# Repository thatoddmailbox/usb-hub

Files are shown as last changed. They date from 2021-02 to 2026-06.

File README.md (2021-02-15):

# usb-hub
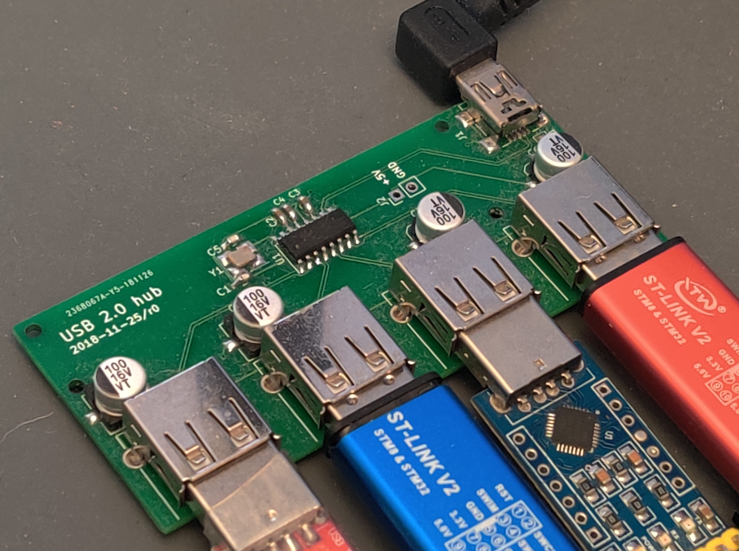
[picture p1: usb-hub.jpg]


A four-port USB 2.0 hub based around the [CoreChips SL2.1A](https://datasheet.lcsc.com/szlcsc/1811151645_CoreChips-SL2-1A_C192893.pdf) IC.

You can choose whether it's bus powered or externally powered with JP1. Soldering JP1 closed selects bus power, while leaving JP1 open means devices are powered with external power, which can be provided through J2.

Note that an external 12 MHz crystal is provided for the SL2.1A. The datasheet claims that the chip also has an internal 12 MHz oscillator that you can use by connecting XIN (pin 16 of the SL2.1) to ground. It's recommended to use the external one, though, as it's more stable. (see the red Chinese text on page 5 of the datasheet)

The port closest to the upstream mini-USB port is port number 1, and the remaining ports are numbered 2 through 4.

## Assembly
This board is fairly easy to assemble with a soldering iron, flux, and solder wick. The main thing to watch out for is that the two sets of electrolytic capacitors, near the output ports, have opposite polarities. The silkscreen has the positive side labeled, so you should make sure the negative side of the capacitor (with the black stripe) is opposite of the positive side (as labeled by a plus on the board).

## Useful links
* [Rev 0 schematic](./mfg/rev0/usb-hub.pdf)
* [Rev 0 BOM](./mfg/rev0/usb-hub.csv)

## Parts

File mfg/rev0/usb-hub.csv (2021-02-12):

Reference | Value | Footprint | Datasheet
U1 | SL2.1A | Housings_SOIC:SOIC-16_3.9x9.9mm_Pitch1.27mm
J1 | USB_B_Mini | Connectors:USB_Mini-B | ~
JP1 | SolderJumper_2_Bridged | Jumper:SolderJumper-2_P1.3mm_Open_TrianglePad1.0x1.5mm | ~
J3 | USB_A | Connectors:USB_A | ~
J2 | Conn_01x02 | Pin_Headers:Pin_Header_Straight_1x02_Pitch2.54mm | ~
J4 | USB_A | Connectors:USB_A | ~
J5 | USB_A | Connectors:USB_A | ~
J6 | USB_A | Connectors:USB_A | ~
Y1 | 12MHz | Crystals:Crystal_SMD_3225-4pin_3.2x2.5mm_HandSoldering | ~
C1 | 12pF | Capacitors_SMD:C_0603_HandSoldering | ~
C5 | 12pF | Capacitors_SMD:C_0603_HandSoldering | ~
C2 | 10uF | Capacitors_SMD:C_0603_HandSoldering | ~
C4 | 10uF | Capacitors_SMD:C_0603_HandSoldering | ~
C3 | 10uF | Capacitors_SMD:C_0603_HandSoldering | ~
C6 | 100uF | Capacitors_SMD:CP_Elec_6.3x5.3 | ~
C7 | 100uF | Capacitors_SMD:CP_Elec_6.3x5.3 | ~
C8 | 100uF | Capacitors_SMD:CP_Elec_6.3x5.3 | ~
C9 | 100uF | Capacitors_SMD:CP_Elec_6.3x5.3 | ~

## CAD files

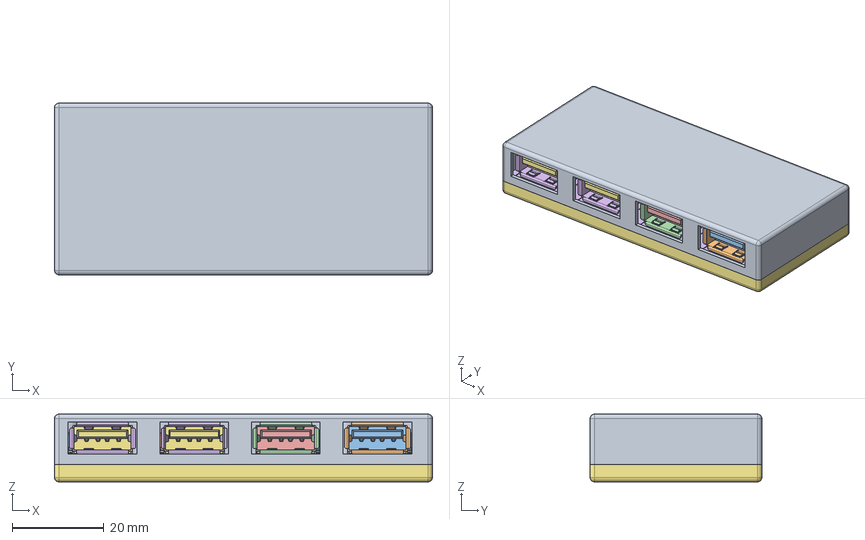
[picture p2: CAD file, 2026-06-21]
case/usb-hub-case.FCStd
82.5 x 37.5 x 14.8 mm
Top Case
USB_A_Molex_67643_Horizontal
USB_A_Molex_67643_Horizontal001
USB_A_Molex_67643_Horizontal002
USB_A_Molex_67643_Horizontal003
USB_A_Molex_67643_Horizontal004
USB_A_Molex_67643_Horizontal005
USB_A_Molex_67643_Horizontal006
USB_A_Molex_67643_Horizontal007
USB_A_Molex_67643_Horizontal008
USB_A_Molex_67643_Horizontal009
USB_A_Molex_67643_Horizontal012
USB_A_Molex_67643_Horizontal013
USB_A_Molex_67643_Horizontal014
USB_A_Molex_67643_Horizontal015
USB_A_Molex_67643_Horizontal016
USB_A_Molex_67643_Horizontal017
USB_A_Molex_67643_Horizontal018
USB_A_Molex_67643_Horizontal019
USB_A_Molex_67643_Horizontal020
USB_A_Molex_67643_Horizontal021
USB_A_Molex_67643_Horizontal024
USB_A_Molex_67643_Horizontal025
USB_A_Molex_67643_Horizontal026
USB_A_Molex_67643_Horizontal027
USB_A_Molex_67643_Horizontal028
USB_A_Molex_67643_Horizontal029
USB_A_Molex_67643_Horizontal030
USB_A_Molex_67643_Horizontal031
USB_A_Molex_67643_Horizontal032
USB_A_Molex_67643_Horizontal033
CP_Elec_63x53
CP_Elec_63x001
CP_Elec_63x002
CP_Elec_63x003
Crystal_SMD_3225-4Pin_3.2x2.5mm_HandSoldering
USB_Mini-B_Lumberg_2486_01_Horizontal
USB_A_Molex_67643_Horizontal036
USB_A_Molex_67643_Horizontal037
USB_A_Molex_67643_Horizontal038
USB_A_Molex_67643_Horizontal039
USB_A_Molex_67643_Horizontal040
USB_A_Molex_67643_Horizontal041
USB_A_Molex_67643_Horizontal042
USB_A_Molex_67643_Horizontal043
USB_A_Molex_67643_Horizontal044
USB_A_Molex_67643_Horizontal045
usb-hub-3dm_silkscreen
usb-hub-3dm_silkscreen001
usb-hub-3dm_silkscreen002
usb-hub-3dm_silkscreen003
usb-hub-3dm_silkscreen004
usb-hub-3dm_silkscreen005
usb-hub-3dm_silkscreen006
usb-hub-3dm_silkscreen007
usb-hub-3dm_silkscreen008
usb-hub-3dm_silkscreen009
usb-hub-3dm_silkscreen010
usb-hub-3dm_silkscreen011
usb-hub-3dm_silkscreen012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

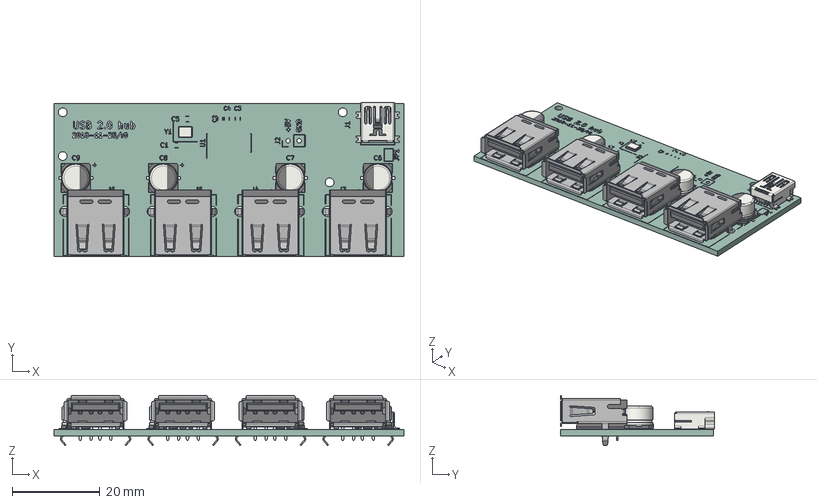
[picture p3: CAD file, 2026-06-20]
mfg/rev0/usb-hub.step
80.0 x 35.3 x 11.5 mm
USB_A_Molex_67643_Horizontal x 4
CP_Elec_63x53 x 4
Crystal_SMD_3225-4Pin_3.2x2.5mm_HandSoldering
USB_Mini-B_Lumberg_2486_01_Horizontal
usb-hub-3dm_silkscreen
usb-hub-3dm_PCB

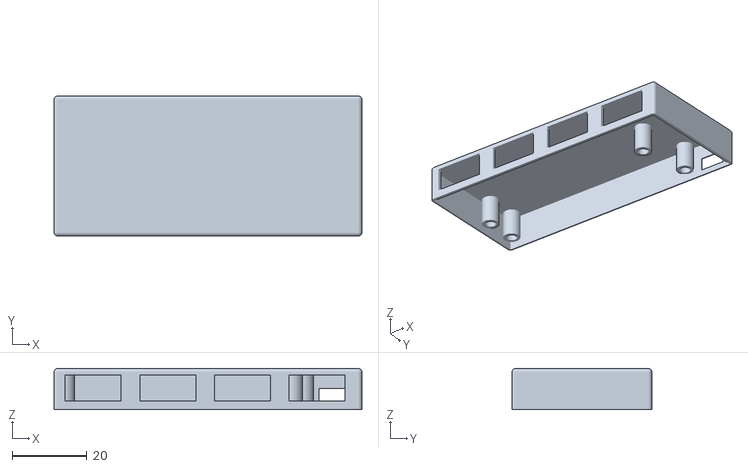
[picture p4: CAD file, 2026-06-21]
case/usb-hub-case-Top Case.stl
82.5 x 37.5 x 11.0

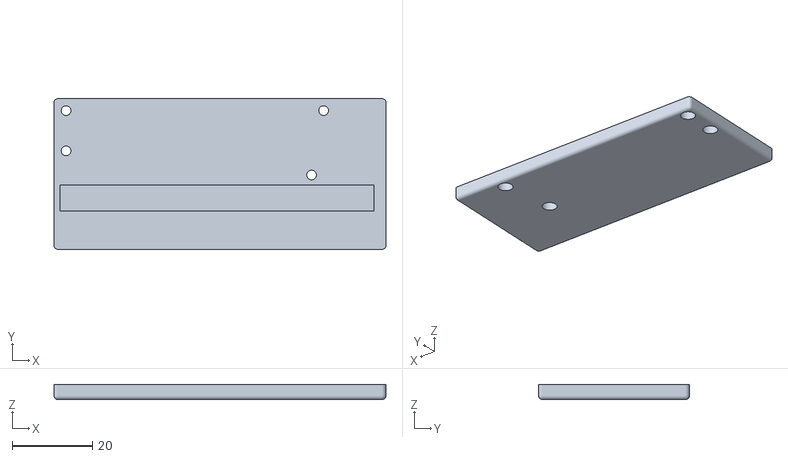
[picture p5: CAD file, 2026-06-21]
case/usb-hub-case-Bottom Case.stl
82.5 x 37.5 x 3.80

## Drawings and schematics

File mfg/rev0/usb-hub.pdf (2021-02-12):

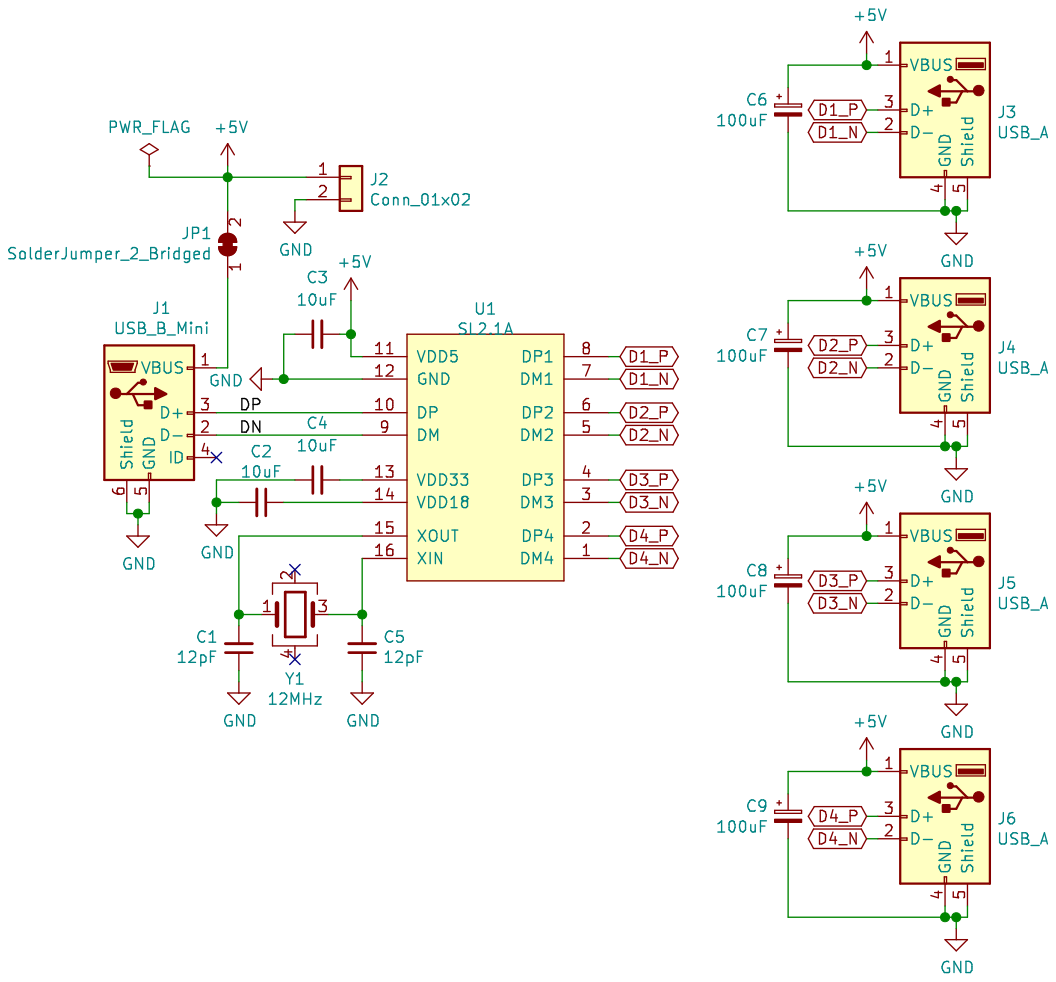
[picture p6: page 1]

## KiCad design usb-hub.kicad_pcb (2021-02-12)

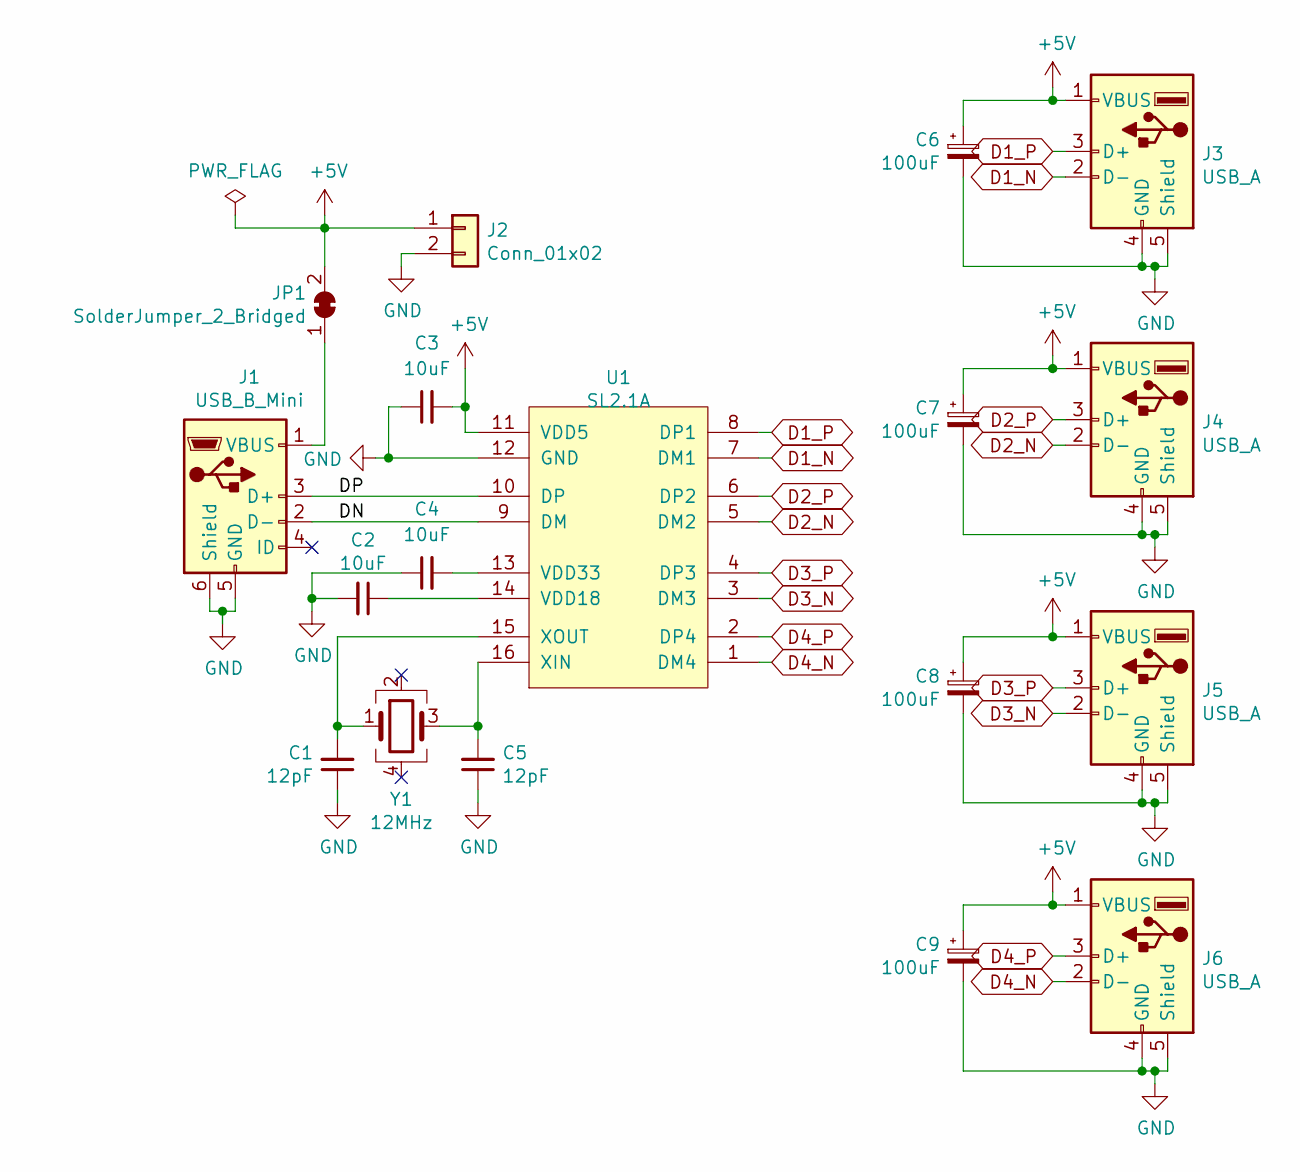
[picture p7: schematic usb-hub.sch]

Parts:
C1, C5: 12pF; C_0603_HandSoldering
C2, C3, C4: 10uF; C_0603_HandSoldering
C6, C7, C8, C9: 100uF; CP_Elec_6.3x5.3
J1: USB_B_Mini; USB_Mini-B
J2: Conn_01x02; Pin_Header_Straight_1x02_Pitch2.54mm
J3, J4, J5, J6: USB_A
JP1: SolderJumper_2_Bridged; SolderJumper-2_P1.3mm_Open_TrianglePad1.0x1.5mm
U1: SL2.1A; SOIC-16_3.9x9.9mm_Pitch1.27mm
Y1: 12MHz; Crystal_SMD_3225-4pin_3.2x2.5mm_HandSoldering

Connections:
+5V: C3.2, C6.1, C7.1, C8.1, C9.1, J2.1, J3.1 (VBUS), J4.1 (VBUS), J5.1 (VBUS), J6.1 (VBUS), JP1.2 (B), U1.11 (VDD5)
/DN: J1.2 (D-), U1.9 (DM)
/DP: J1.3 (D+), U1.10 (DP)
D1_N: J3.2 (D-), U1.7 (DM1)
D1_P: J3.3 (D+), U1.8 (DP1)
D2_N: J4.2 (D-), U1.5 (DM2)
D2_P: J4.3 (D+), U1.6 (DP2)
D3_N: J5.2 (D-), U1.3 (DM3)
D3_P: J5.3 (D+), U1.4 (DP3)
D4_N: J6.2 (D-), U1.1 (DM4)
D4_P: J6.3 (D+), U1.2 (DP4)
GND: C1.1, C2.2, C3.1, C4.1, C5.1, C6.2, C7.2, C8.2, C9.2, J1.5 (GND), J1.6 (Shield), J2.2, J3.4 (GND), J3.5 (Shield), J4.4 (GND), J4.5 (Shield), J5.4 (GND), J5.5 (Shield), J6.4 (GND), J6.5 (Shield), U1.12 (GND)
unnamed: C1.2, U1.15 (XOUT), Y1.1
unnamed: C2.1, U1.14 (VDD18)
unnamed: C4.2, U1.13 (VDD33)
unnamed: C5.2, U1.16 (XIN), Y1.3
unnamed: J1.1 (VBUS), JP1.1 (A)

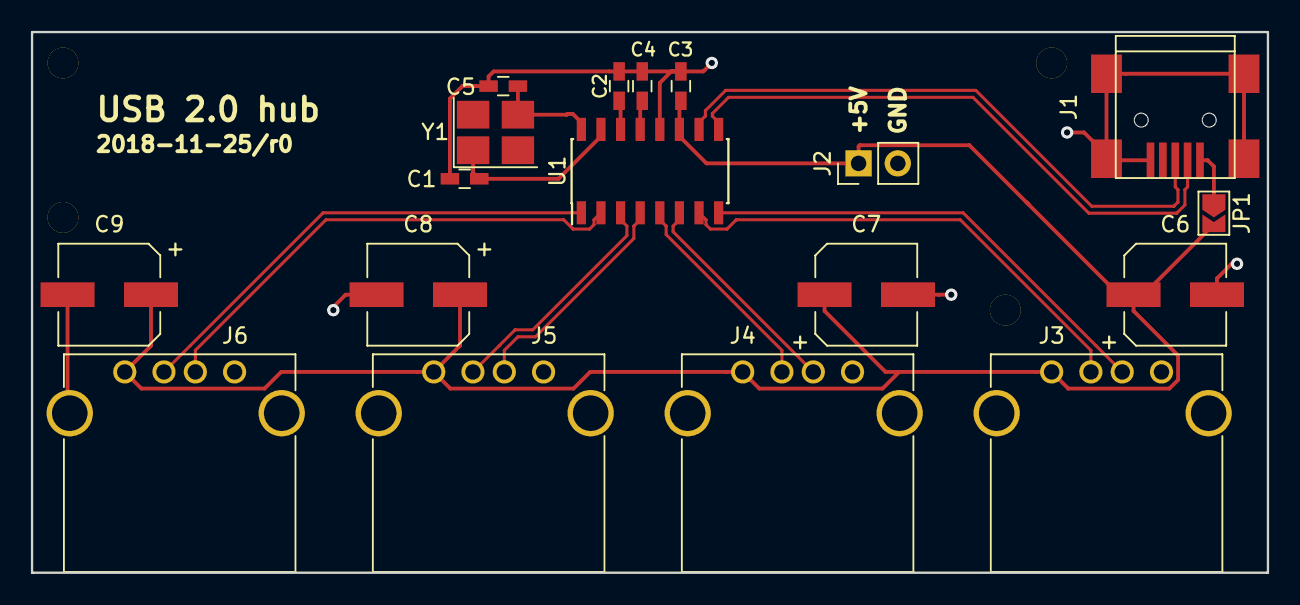
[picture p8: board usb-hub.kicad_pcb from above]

Board: 2 copper layers, 80.0 x 35.0 mm, 18 parts (0 on the bottom side), 17 nets.

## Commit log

2021-02-12 commit rev 0 schematic, pcb, and gerbers
    [usb-hub-B.Cu.gbr, usb-hub-B.Mask.gbr, usb-hub-B.SilkS.gbr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]
2021-02-12 add pdf of rev 0 schematic
2021-02-12 add csv bom file for rev 0
    [usb-hub.csv]
2021-02-12 move manufacturing files into rev0 folder
    [usb-hub-B.Cu.gbr, usb-hub-B.Mask.gbr, usb-hub-B.SilkS.gbr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]
2021-02-12 readme: add links to schematic and bom
2021-02-12 readme: note about bus/external power
2021-02-13 readme: mention the pin to use for internal xtal
2021-02-13 readme: add assembly section
2026-06-20 add step file for rev 0
    [usb-hub.step]
2026-06-21 add case files (freecad project and stls)
    [usb-hub-case-Bottom Case.stl, usb-hub-case-Top Case.stl, usb-hub-case.FCStd]
